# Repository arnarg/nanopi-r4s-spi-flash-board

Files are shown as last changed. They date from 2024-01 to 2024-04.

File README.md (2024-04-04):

# NanoPi R4S SPI Flash Board

A small PCB adding an SPI Flash and i2c EEPROM using the GPIO header.

In order to be low-profile enough to fit inside the metal enclosure the pin header used is [Harwin M20-7810545](https://www.harwin.com/products/M20-7810545/).

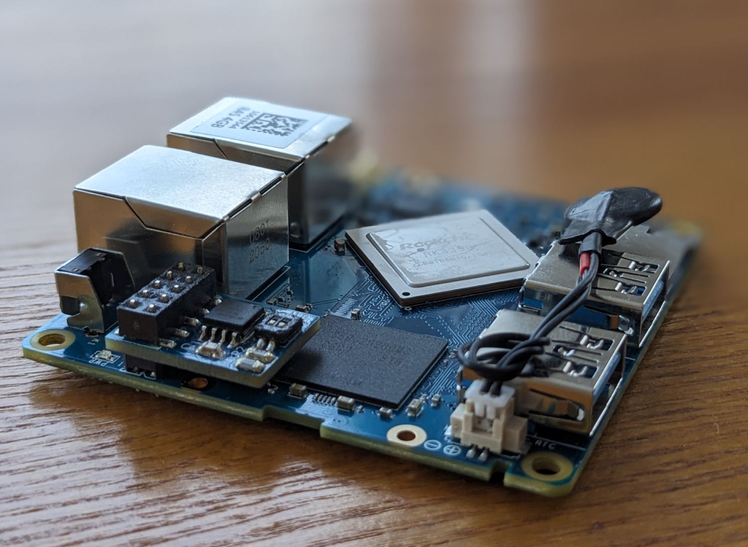
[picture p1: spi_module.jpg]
NanoPI R4S SPI flash module attached to the GPIO header


Blog post: https://codedbearder.com/posts/nanopi-r4s-spi-flash/

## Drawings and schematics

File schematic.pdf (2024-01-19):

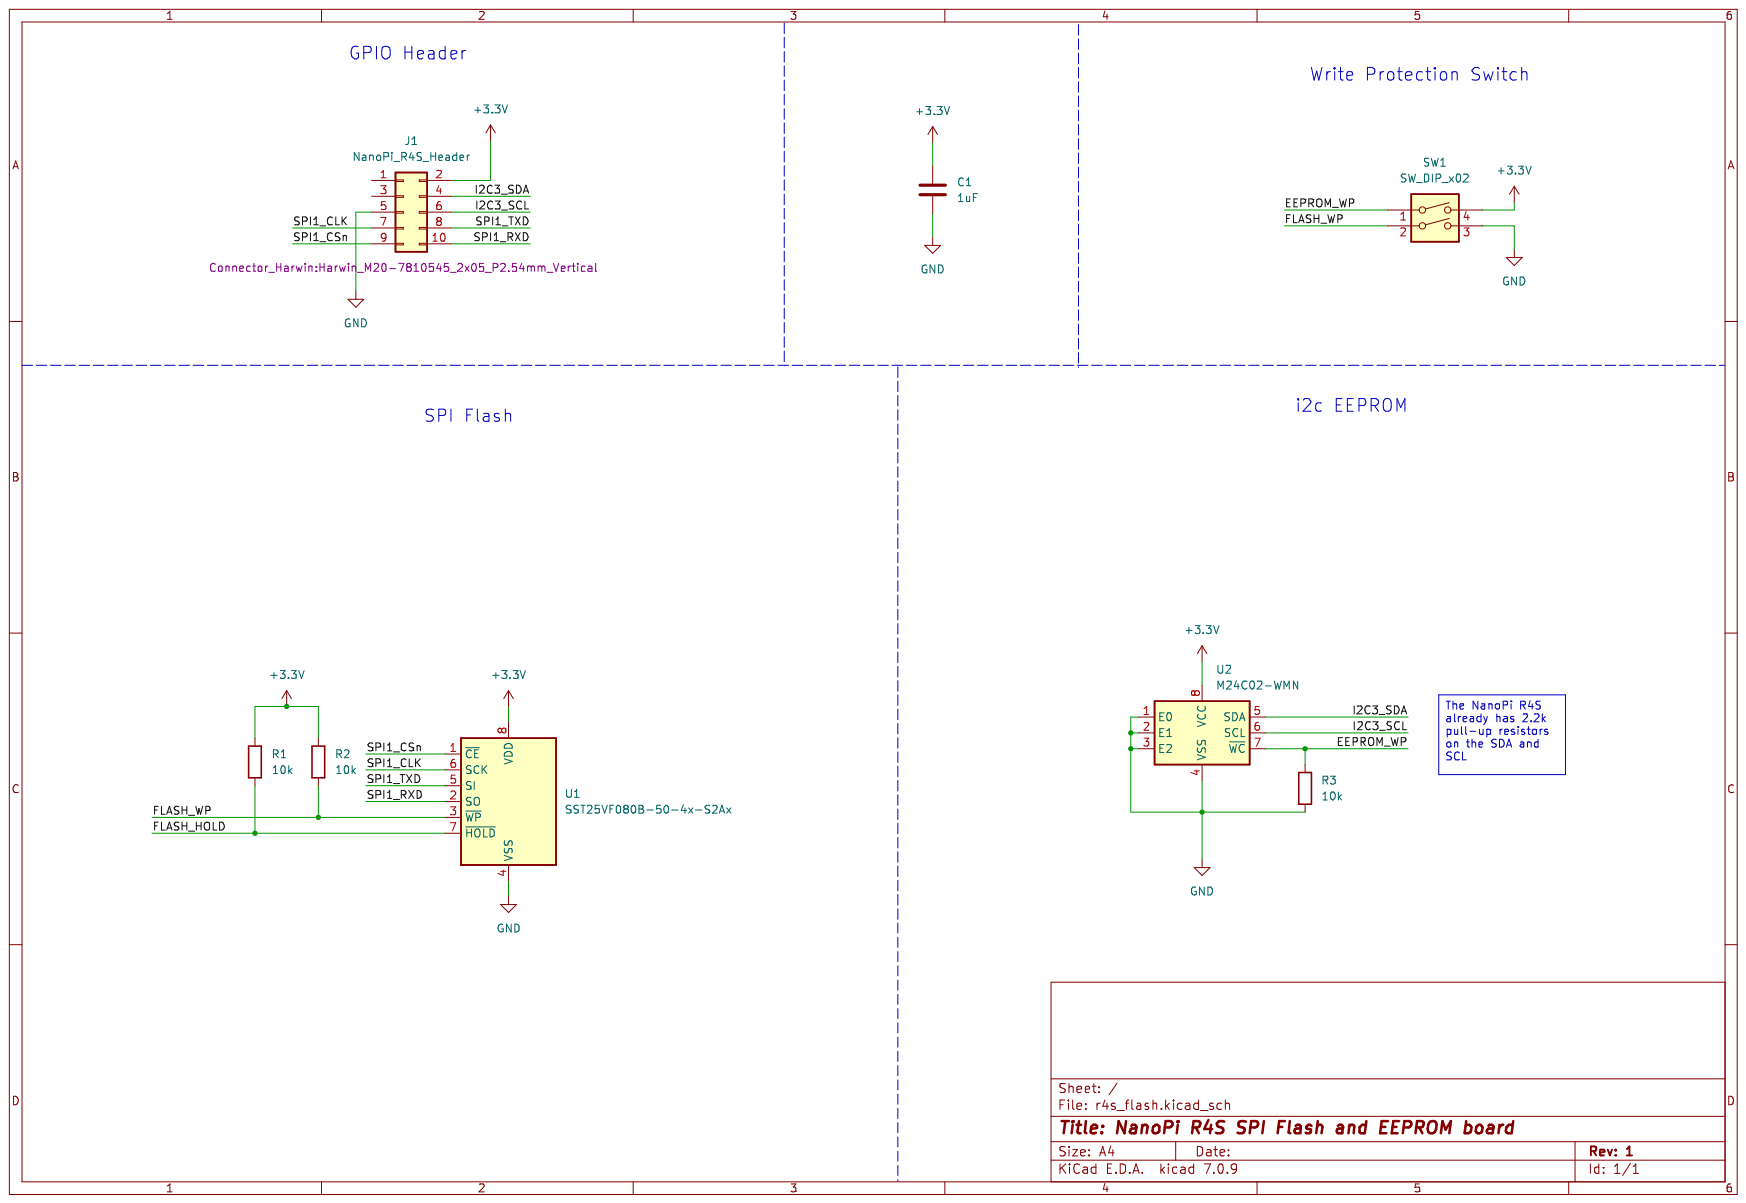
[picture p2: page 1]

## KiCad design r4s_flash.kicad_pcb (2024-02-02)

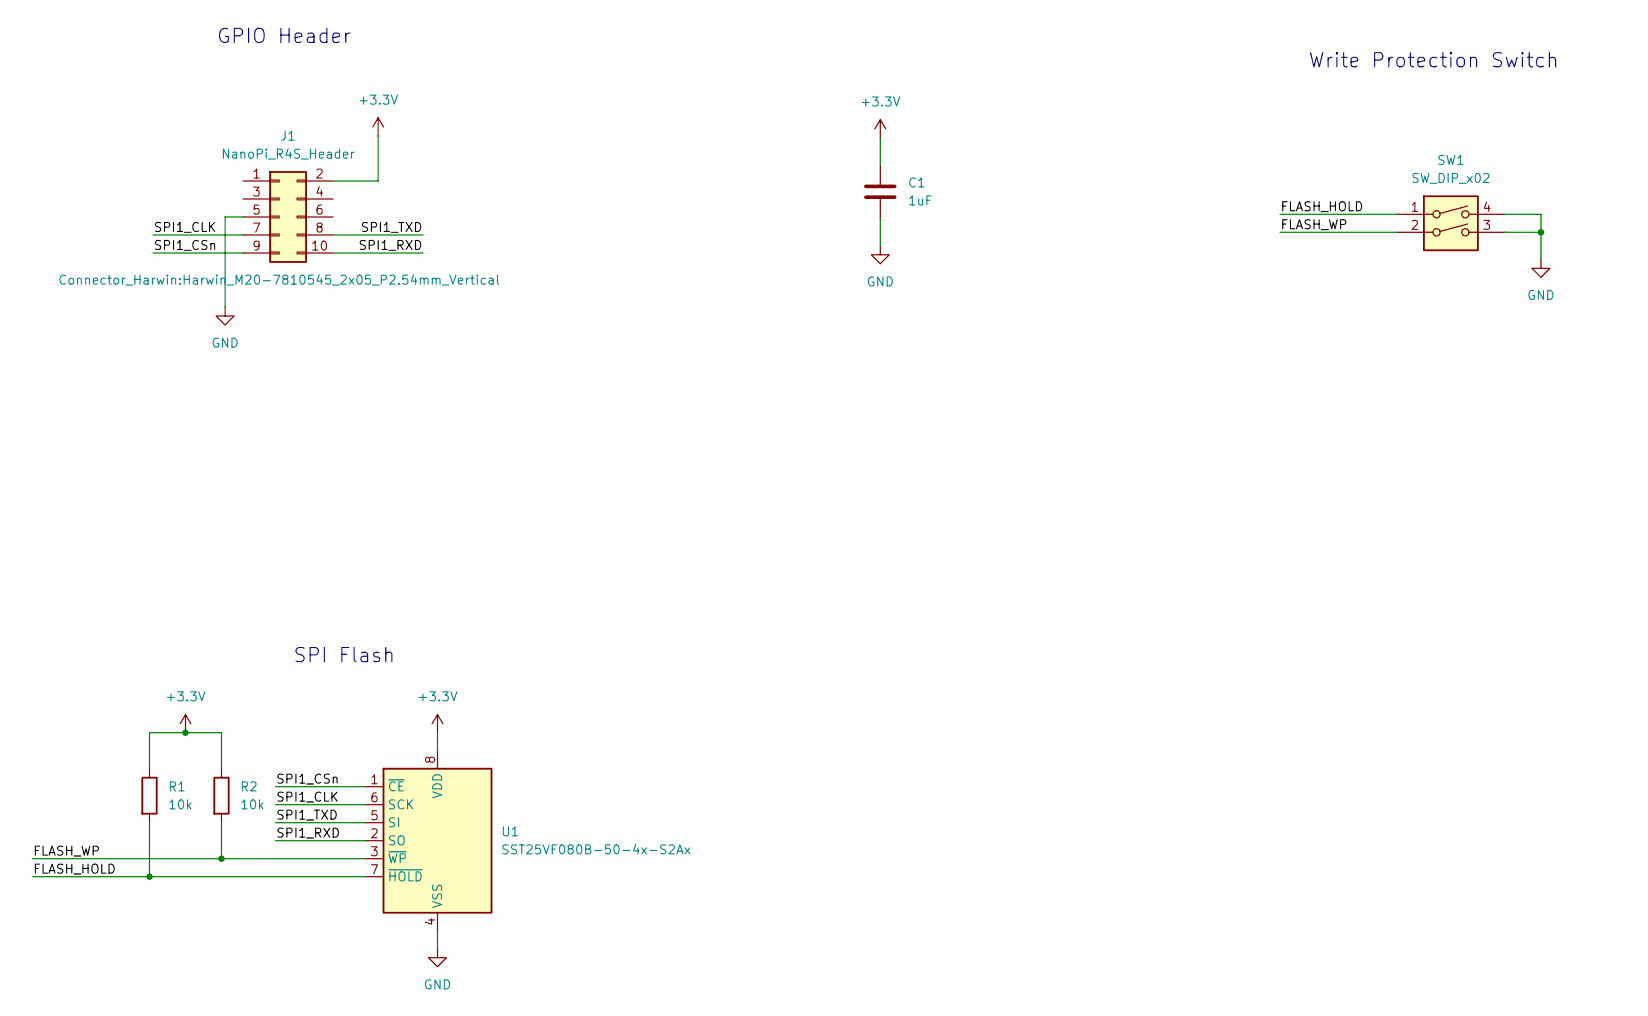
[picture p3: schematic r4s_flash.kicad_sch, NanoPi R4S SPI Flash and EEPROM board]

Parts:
C1: 1uF; C_0805_2012Metric_Pad1.18x1.45mm_HandSolder
J1: NanoPi_R4S_Header; Harwin_M20-7810545_2x05_P2.54mm_Vertical
R1, R2: 10k; R_0805_2012Metric_Pad1.20x1.40mm_HandSolder
SW1: SW_DIP_x02; SW_DIP_SPSTx02_Slide_Omron_A6H-2101_W6.15mm_P1.27mm
U1: SST25VF080B-50-4x-S2Ax; SOIC-8_5.275x5.275mm_P1.27mm

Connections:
+3.3V: C1.1, J1.2, R1.1, R2.1, U1.8 (VDD)
/FLASH_HOLD: R1.2, SW1.1, U1.7 (~HOLD)
/FLASH_WP: R2.2, SW1.2, U1.3 (~WP)
/SPI1_CLK: J1.7, U1.6 (SCK)
/SPI1_CSn: J1.9, U1.1 (~CE)
/SPI1_RXD: J1.10, U1.2 (SO)
/SPI1_TXD: J1.8, U1.5 (SI)
GND: C1.2, J1.5, SW1.3, SW1.4, U1.4 (VSS)

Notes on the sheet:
GPIO Header
Write Protection Switch
SPI Flash

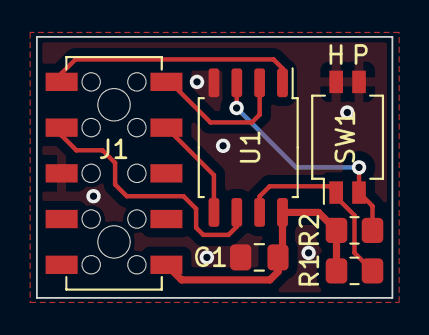
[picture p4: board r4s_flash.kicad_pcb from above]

Board: 2 copper layers, 19.8 x 14.5 mm, 6 parts (0 on the bottom side), 8 nets.

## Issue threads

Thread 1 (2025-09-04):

Boot from USB ?

jeandestouches, 2025-09-04:
Hello,
So basically, I broke the micro sd port on my r4s, I was looking for an alternative to boot, maybe using usb instead.
Before investing time and ordering parts, I'd like to know if it is possible to boot from one of the two usb ports instead of micro sd once the bootloader is loaded from the SPI NOR flash. Can it work ?
Thanks for your very interesting guide.
Cheers

jeandestouches, 2025-09-04:
Great ! :) Then I'll give it a try later. I might have some SST25VF080B somewhere...
